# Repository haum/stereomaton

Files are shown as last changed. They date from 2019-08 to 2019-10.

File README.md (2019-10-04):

# Stereomaton

It is an itinerant self-service stereoscopic (3D) photo automaton.

## Status

Working prototype

It was tested in a festival and it worked wonderfully.

## Related links

Presentation of the project: https://www.crowdsupply.com/virt2real/stereopi/updates/field-report-stereomaton

First photos in the festival: https://photos.haum.org/albums/teriaki2019/

Presentation of the case: https://www.crowdsupply.com/virt2real/stereopi/updates/field-report-follow-up-making-a-case-for-stereomaton

## Overview

Users can use the stereomaton to take photographs of themselves and view them in 3D thanks to appropriate equipment (3D display, cardboard, vr headset, etc.) of their own.
The stereomaton generates a (readable) code they can use to retrieve the photograph on a specific webpage.

## Hardware & base software

The stereomaton is based on [StereoPi](http://stereopi.com/) hardware (board + two cameras)
with SLP variant image of Raspbian (version 0.2.3 used)
with a 3.5" SPI [LCD display](http://www.lcdwiki.com/3.5inch_RPi_Display) using fb_ili9486 driver.

Note that LCD driver and its configuration, touchscreen driver, python as well as evdev, opencv, numpy and pycairo modules are assumed installed on the system for the code present in this repository.

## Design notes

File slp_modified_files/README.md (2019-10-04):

These files are added (or replaced) in SLP.

You might also need to add space on the partition and install a few packages:
```
mount -o remount,rw /
apt update
apt install python3-numpy
apt install python3-pip
pip3 install evdev
pip3 install pycairo
pip3 install opencv-python
apt install libcblas-dev libhdf5-dev libhdf5-serial-dev libatlas-base-dev libjasper-dev libqtgui4 libqt4-test
```

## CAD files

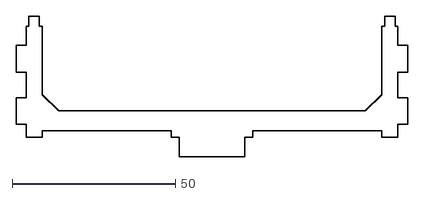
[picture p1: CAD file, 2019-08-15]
case/exported_parts/p_tongue.dxf
120.0 x 43.0

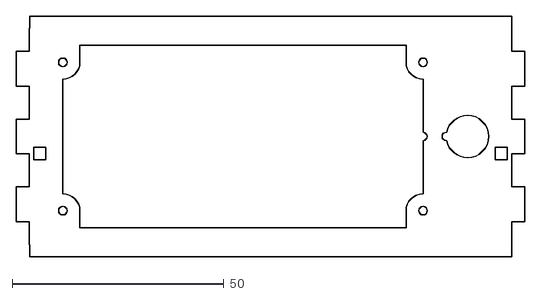
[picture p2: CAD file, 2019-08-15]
case/exported_parts/p_stpiholder.dxf
120.0 x 56.7

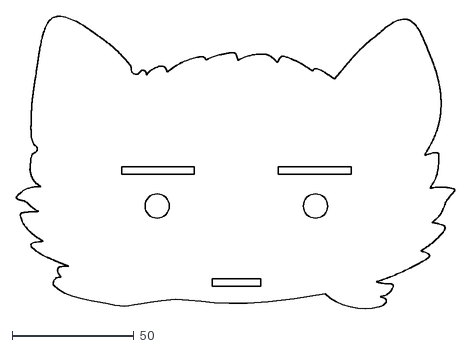
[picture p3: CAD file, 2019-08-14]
case/exported_parts/p_deco.dxf
180.0 x 120.0

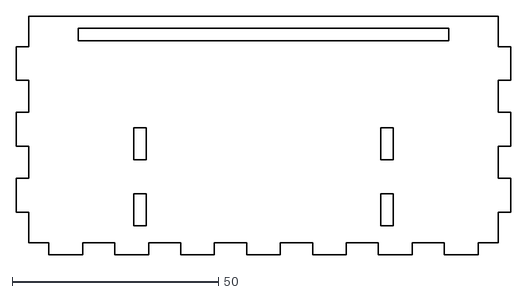
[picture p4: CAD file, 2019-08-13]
case/exported_parts/p_bottom.dxf
120.0 x 58.0

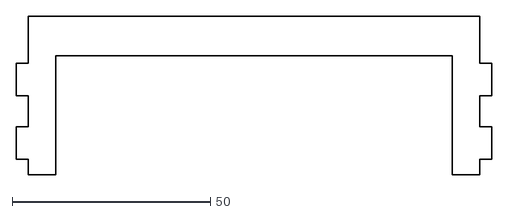
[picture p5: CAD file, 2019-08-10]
case/exported_parts/p_back.dxf
120.0 x 40.0

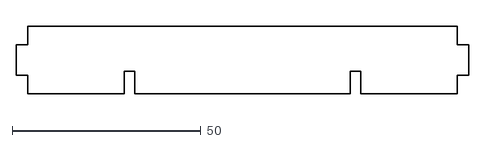
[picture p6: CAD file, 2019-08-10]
case/exported_parts/p_screen_top.dxf
120.0 x 18.0

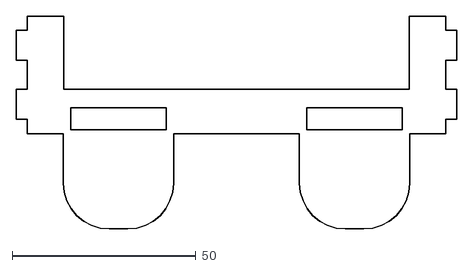
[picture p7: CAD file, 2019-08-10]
case/exported_parts/p_caps.dxf
120.0 x 58.0

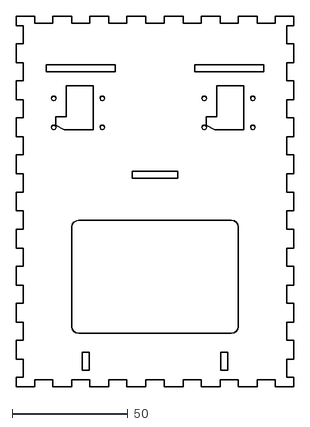
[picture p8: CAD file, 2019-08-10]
case/exported_parts/p_front.dxf
120.0 x 160.0

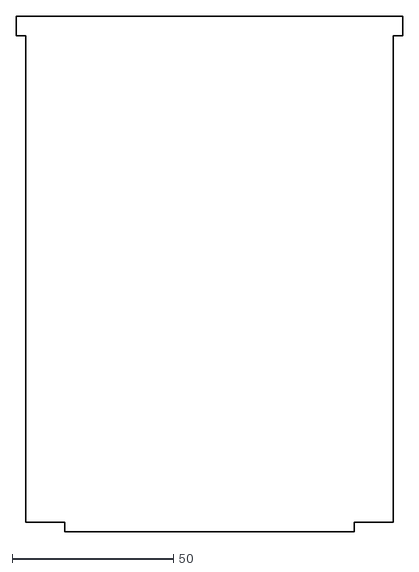
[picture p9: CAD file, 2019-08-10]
case/exported_parts/p_door.dxf
120.0 x 160.0

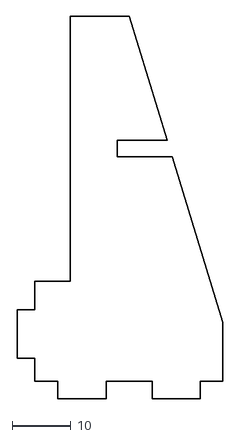
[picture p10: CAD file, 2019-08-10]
case/exported_parts/p_screen_bottom.dxf
34.9 x 65.0

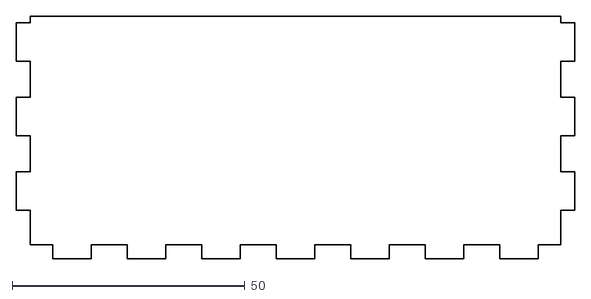
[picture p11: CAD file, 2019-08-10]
case/exported_parts/p_top.dxf
120.0 x 52.0

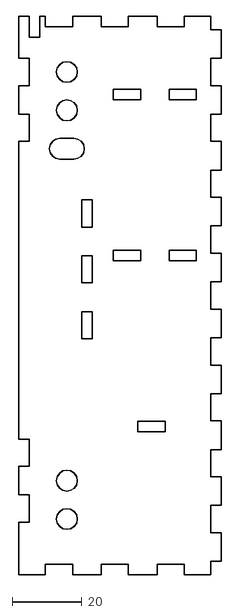
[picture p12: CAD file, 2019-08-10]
case/exported_parts/p_side.dxf
58.0 x 160.0

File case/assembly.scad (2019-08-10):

explode = 0.01;
opacity = 0.5;
show_door = true;
show_box = true;
show_deco = true;
show_battery = false;
show_stereopi = true;
simplified_stereopi = true;

module bottom() {
    linear_extrude(height = 3)
        import("exported_parts/p_bottom.dxf");
}

module sideL() {
    rotate([90, 0, -90])
        linear_extrude(height = 3)
            import("exported_parts/p_side.dxf");
}

module sideR() {
    rotate([90, 0, -90])
        translate([0, 0, -3])
            linear_extrude(height = 3)
                import("exported_parts/p_side.dxf");
}

module front() {
    rotate([90, 0, 0])
        linear_extrude(height = 3)
            import("exported_parts/p_front.dxf");
}

module backT() {
    rotate([90, 0, 0])
        translate([0, 0, -3])
            linear_extrude(height = 3)
                import("exported_parts/p_back.dxf");
}

module backB() {
    rotate([-90, 0, 0])
        linear_extrude(height = 3)
            import("exported_parts/p_back.dxf");
}

module top() {
    translate([0, 0, -3])
        linear_extrude(height = 3)
            import("exported_parts/p_top.dxf");
}

module door() {
    rotate([90, 0, 0])
        translate([0, 0, -3])
            linear_extrude(height = 3)
                import("exported_parts/p_door.dxf");
}

module caps() {
    linear_extrude(height = 3)
        import("exported_parts/p_caps.dxf");
}

module tongue() {
    linear_extrude(height = 3)
        import("exported_parts/p_tongue.dxf");
}

module screen_bottomL() {
    rotate([90, 0, 90])
        linear_extrude(height = 3)
            import("exported_parts/p_screen_bottom.dxf");
}

module screen_bottomR() {
    rotate([90, 0, 90])
        translate([0, 0, -3])
            linear_extrude(height = 3)
                import("exported_parts/p_screen_bottom.dxf");
}

module screen_top() {
    linear_extrude(height = 3)
        import("exported_parts/p_screen_top.dxf");
}

module stpiholder() {
    rotate([90, 0, 0])
        linear_extrude(height = 3)
            import("exported_parts/p_stpiholder.dxf");
}

module deco() {
    rotate([90, 0, 0])
        linear_extrude(height = 3)
            import("exported_parts/p_deco.dxf");
}

module assembly() {
    if (show_box) {
        translate([0, 0, -explode]) bottom();
        translate([60 + explode, 0, 0]) sideL();
        translate([-60 - explode, 0, 0]) sideR();
        translate([0, 26 + explode, 120]) backT();
        translate([0, 26 + explode, 43]) backB();
        translate([0, 0, 160 + explode]) top();
    }
    translate([0, -26 - explode, 0]) front();
    translate([0, -25, 136]) caps();
    translate([0, -26, 90]) tongue();
    translate([28.5, -29, 0]) screen_bottomL();
    translate([-28.5, -29, 0]) screen_bottomR();
    translate([0, -18 + explode, 41]) screen_top();
    translate([0, 11 + explode, 62]) stpiholder();
    if (show_door)
        translate([0, 23, 30 * explode]) door();
    if (show_deco)
        translate([0, -29 - 2 * explode, 90]) deco();
}

module stereopi() {
    translate([-6.5, -8.9, 85.9]) {
        rotate([90, 180, 0]) {
            translate([-45, -21.6, -11.39])
                cube([90, 40, 1.2]);
            translate([-36, -21.6, -17.5])
                color("red") cube([72,36.1,7]);
            if (simplified_stereopi) {
                translate([-14, -21.6, -10])
                    cube([34,21,15.7]);
            } else {
                import("/tmp/sp.stl"); // Requieres the STL stereopi model to display it.
            }
            translate([32.5, 10.85, 17.1]) {
                rotate([0, 180, 0]) {
                    union() {
                        cube([85,55,5.5]);
                        translate([7, 0, 5.5])
                            cube([33,6,18]);
                        translate([19,7,5.5])
                            color("red") cube([41,38,1.5]);
                        translate([1.5, 2,-0.1])
                            color("white") cube([75, 51, 0.1]);
                    }
                }
            }
        }
    }
}

module battery() {
    translate([-10, 9, 169])
        difference() {
            cube([140, 75, 18], center=true);
            translate([-55, -27, 0])
                cylinder(r=3.5, h=20, center=true);
        }
}

%color([0.85, 0.79, 0.69, opacity])
    assembly();
if (show_battery) battery();
if (show_stereopi) stereopi();

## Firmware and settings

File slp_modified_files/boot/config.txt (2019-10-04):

# For more options and information see
# http://rpf.io/configtxt
# Some settings may impact device functionality. See link above for details

# uncomment if you get no picture on HDMI for a default "safe" mode
#hdmi_safe=1

# uncomment this if your display has a black border of unused pixels visible
# and your display can output without overscan
disable_overscan=1

# uncomment the following to adjust overscan. Use positive numbers if console
# goes off screen, and negative if there is too much border
#overscan_left=16
#overscan_right=16
#overscan_top=16
#overscan_bottom=16

# uncomment to force a console size. By default it will be display's size minus
# overscan.
#framebuffer_width=1280
#framebuffer_height=720

# uncomment if hdmi display is not detected and composite is being output
#hdmi_force_hotplug=1

# uncomment to force a specific HDMI mode (this will force VGA)
#hdmi_group=1
#hdmi_mode=1

# uncomment to force a HDMI mode rather than DVI. This can make audio work in
# DMT (computer monitor) modes
#hdmi_drive=2

# uncomment to increase signal to HDMI, if you have interference, blanking, or
# no display
#config_hdmi_boost=4

# uncomment for composite PAL
#sdtv_mode=2

#uncomment to overclock the arm. 700 MHz is the default.
#arm_freq=800

# Uncomment some or all of these to enable the optional hardware interfaces
dtparam=i2c_arm=on
#dtparam=i2s=on
dtparam=spi=on

# Uncomment this to enable the lirc-rpi module
#dtoverlay=lirc-rpi

# Additional overlays and parameters are documented /boot/overlays/README

# Enable audio (loads snd_bcm2835)
#dtparam=audio=on
start_x=1
gpu_mem=192
enable_uart=1

dtoverlay=pi3-disable-bt
disable_splash=1

dtoverlay=dwc2
dtoverlay=tft35a:rotate=90

dtoverlay=vc4-fkms-v3d

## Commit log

2019-07-25 Add basic touchscreen mechanism with screen chains
2019-08-10 Add plans to laser cut a box
    [assembly.scad, p_back.dxf, p_bottom.dxf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]
2019-08-10 Add decoration mask
    [assembly.scad, p_deco.dxf]
2019-08-12 Rename 'box' folder into 'case'
    [assembly.scad, p_back.dxf, p_bottom.dxf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]
2019-08-13 Fix length of slot for right ribbon on tongue part
    [p_tongue.dxf]
2019-08-13 Fix slot length in bottom part of the case
    [p_bottom.dxf]
2019-08-14 Reduce laser width compensation on deco for easier removal
    [p_deco.dxf]
2019-08-14 Disable camera after photo is taken
2019-08-15 Fix StereoPi fixation
    [p_stpiholder.dxf, p_tongue.dxf]
2019-10-04 Add annex files to rebuild stereomaton system
    [config.txt]
2019-10-04 Add link to case field report
